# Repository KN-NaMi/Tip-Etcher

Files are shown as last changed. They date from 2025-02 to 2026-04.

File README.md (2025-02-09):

# Tip Etcher for Scanning Tunneling Microscopy (STM)

## Overview
This project is a **Tip Etcher** designed for the fabrication of fine tungsten tips required for **Scanning Tunneling Microscopy (STM)**. The inspiration for this project comes from the [Zyrus Tip Etcher](https://hackaday.io/project/191941-zyrus-tip-etcher-for-scanning-tunneling-microscopy) project, with modifications to improve performance and usability.

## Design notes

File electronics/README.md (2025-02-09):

# PCB Design

This folder contains the PCB design files for the Tip Etcher.

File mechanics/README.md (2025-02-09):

# 3D Model

This folder contains the 3D model files for the Tip Etcher assembly. These models are useful for visualization, 3D printing, and mechanical integration.

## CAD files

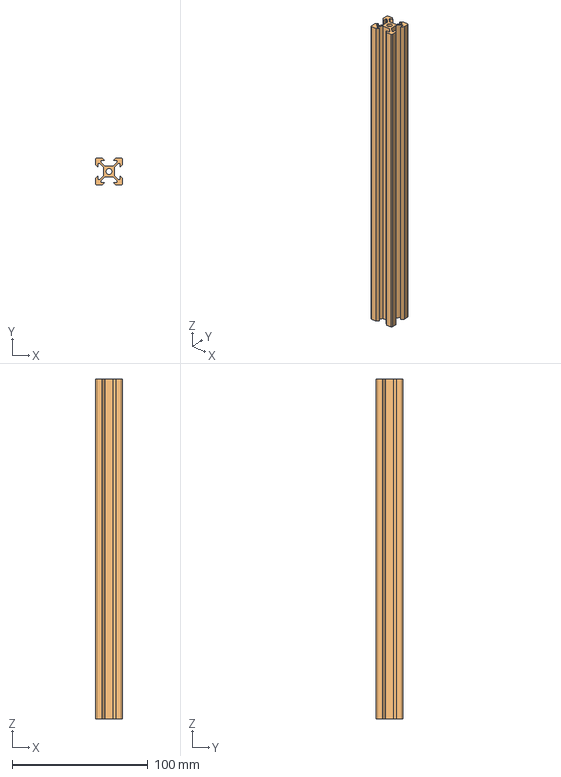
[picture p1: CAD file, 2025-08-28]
mechanics/frame/assembly-frame.FCStd
20.0 x 20.0 x 250.0 mm
2020_150mm v2
2020_250mm v2

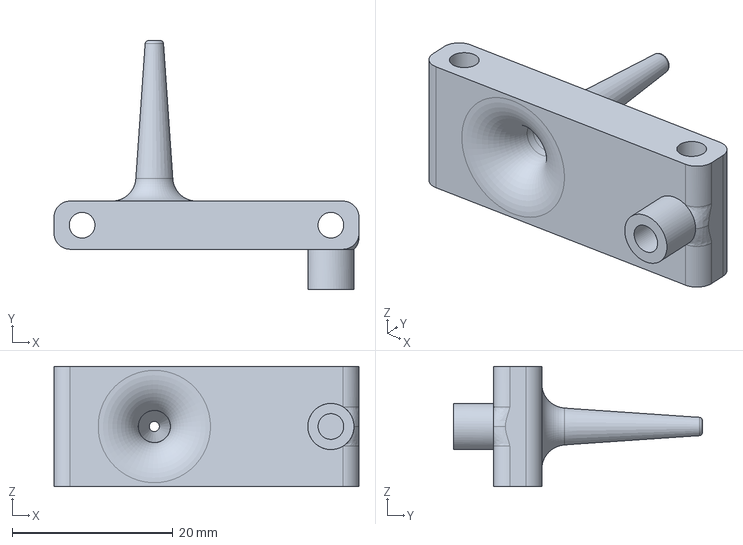
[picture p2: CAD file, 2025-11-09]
cad/mechanism/funnel.FCStd
38.0 x 31.0 x 15.0 mm

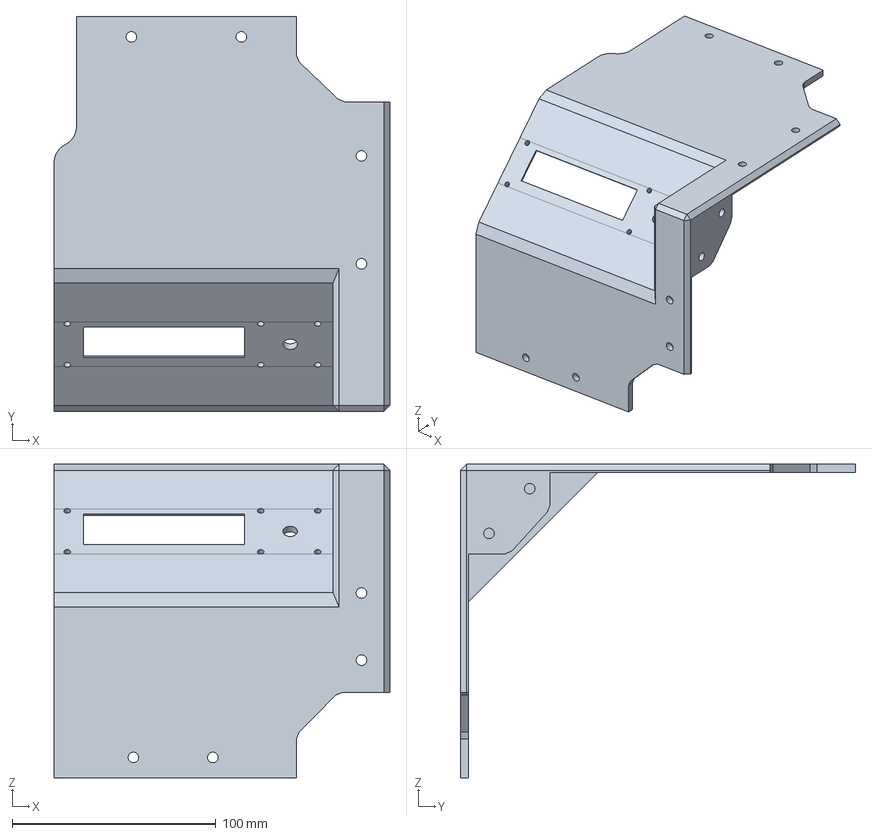
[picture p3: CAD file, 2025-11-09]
cad/Screen/Screen_v3.FCStd
165.0 x 194.0 x 154.0 mm

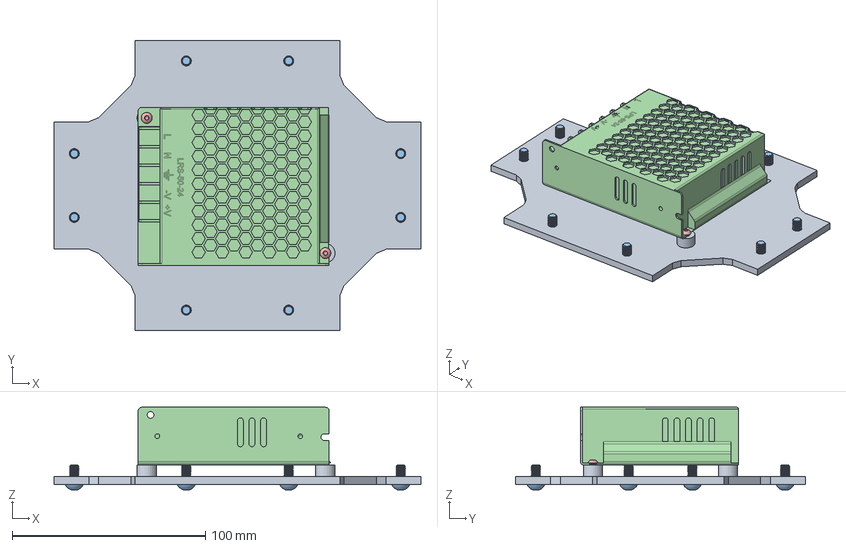
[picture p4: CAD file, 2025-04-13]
mechanics/power-supply/psu-mount.FCStd
190.0 x 150.0 x 42.8 mm
mount
M3x5.74-Insert x 2
M5x10-Screw x 8
MW LRS-50-24
M3x6-Screw x 2

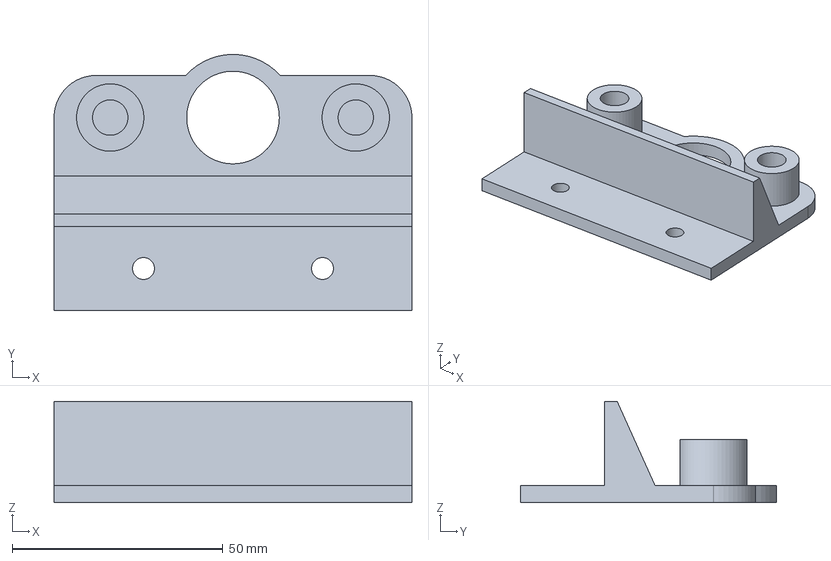
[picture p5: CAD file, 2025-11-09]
cad/mechanism/top.FCStd
85.0 x 60.8 x 24.0 mm

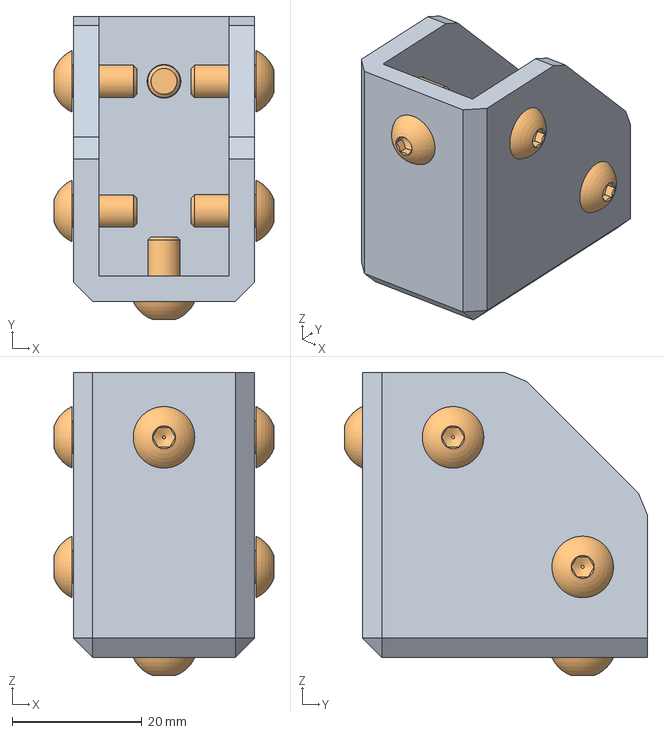
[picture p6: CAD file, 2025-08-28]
mechanics/frame/L-mount.FCStd
33.9 x 46.8 x 46.8 mm
M5x10-Screw x 6

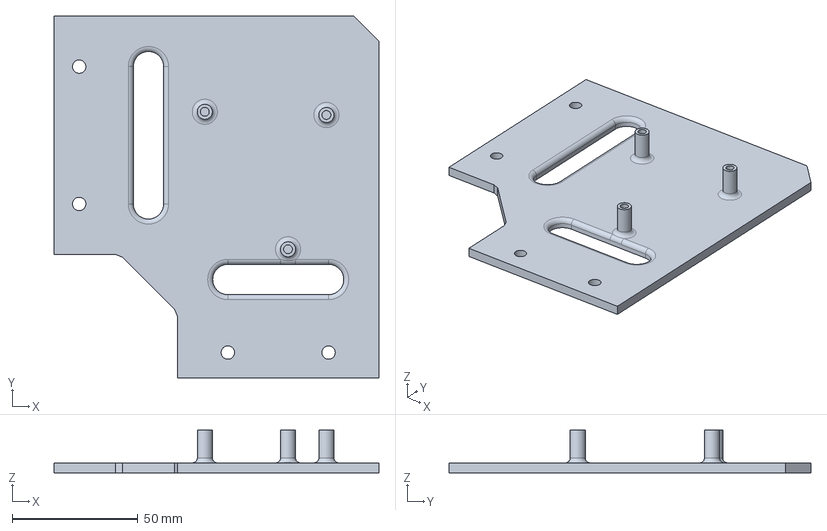
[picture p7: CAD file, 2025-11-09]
cad/mechanism/stm_mount.FCStd
129.0 x 143.5 x 17.0 mm

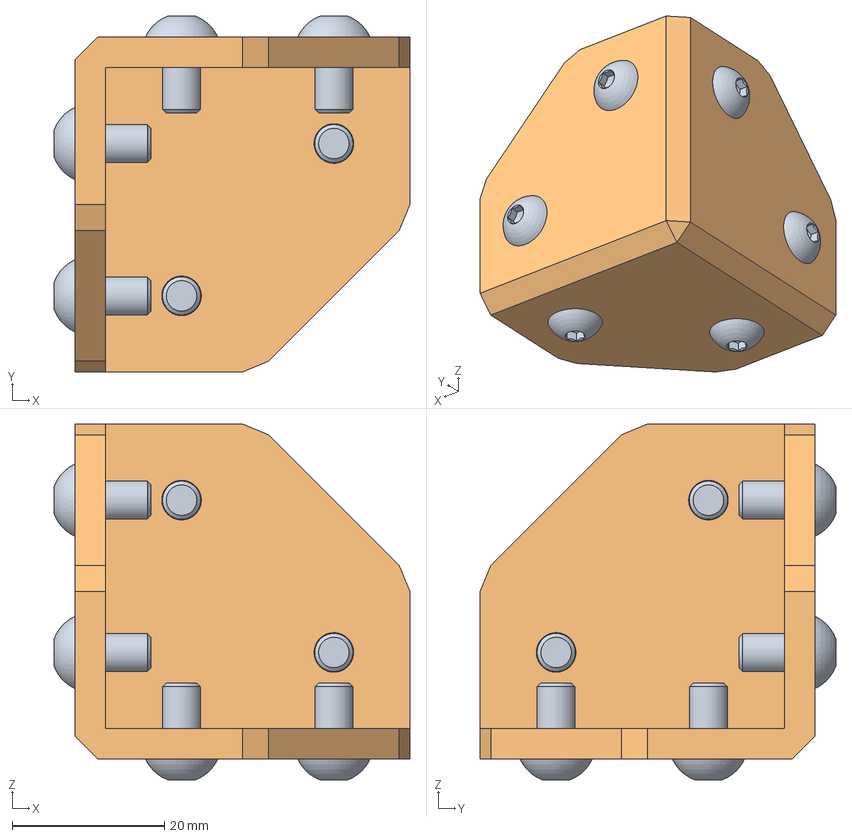
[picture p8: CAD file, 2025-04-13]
mechanics/frame/corner-mount.FCStd
46.8 x 46.8 x 46.8 mm
M5x10-Screw x 6

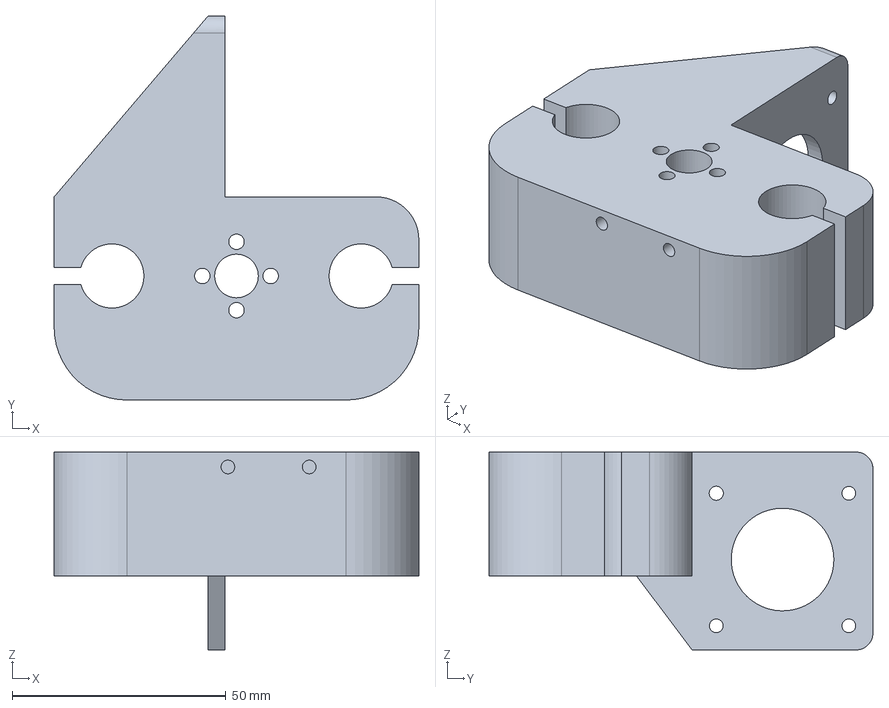
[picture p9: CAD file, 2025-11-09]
cad/mechanism/head.FCStd
85.3 x 89.8 x 46.3 mm

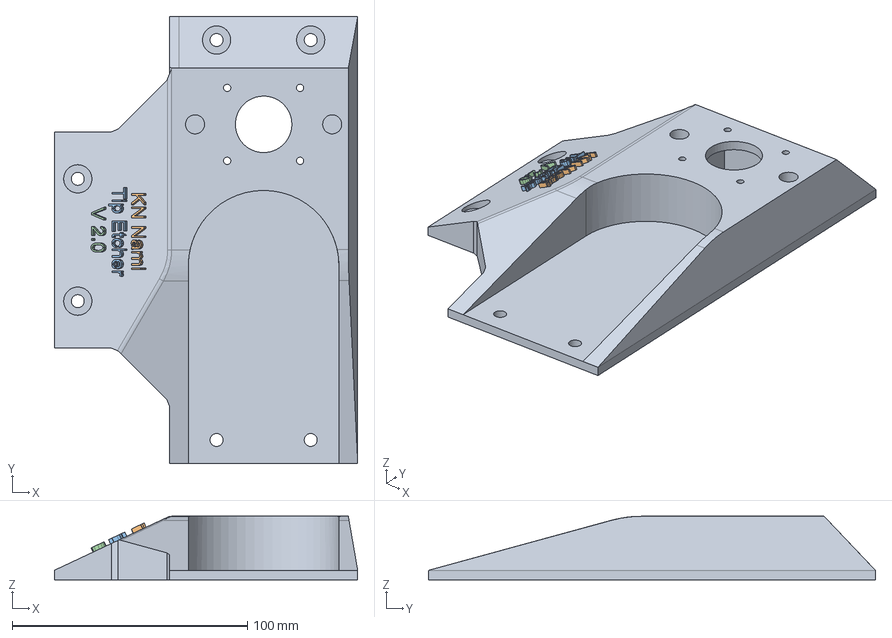
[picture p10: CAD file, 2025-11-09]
cad/mechanism/base.FCStd
129.0 x 190.0 x 27.0 mm

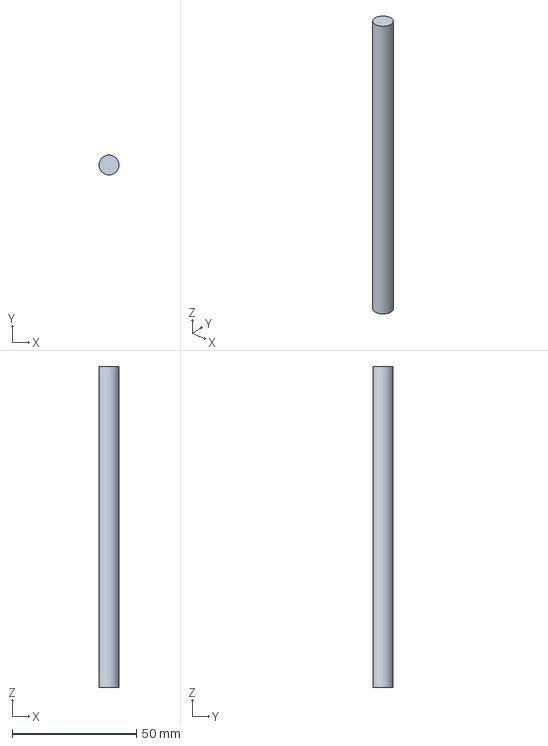
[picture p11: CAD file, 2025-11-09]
cad/mechanism/rod.FCStd
7.99 x 8.00 x 129.0 mm

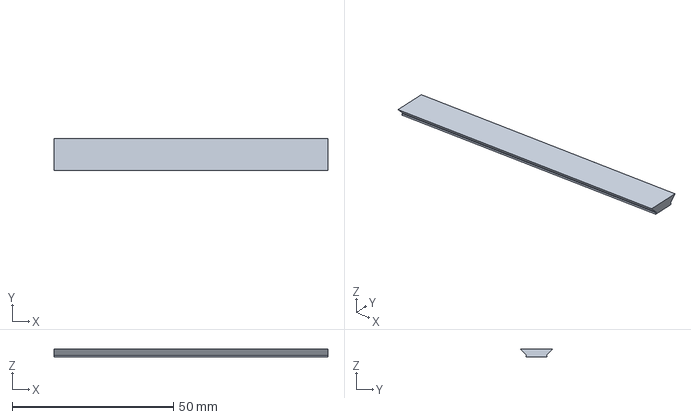
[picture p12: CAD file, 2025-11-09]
cad/mechanism/profile_cover.FCStd
85.0 x 10.0 x 2.50 mm

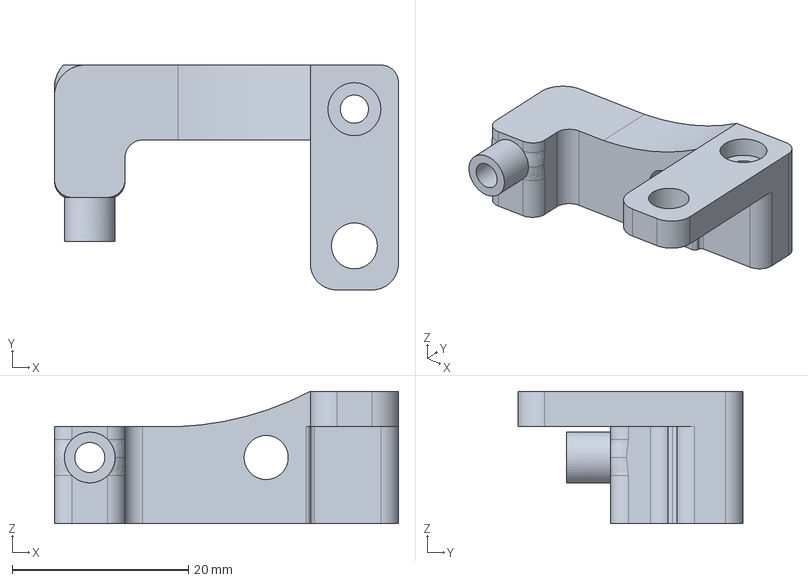
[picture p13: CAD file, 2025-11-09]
cad/mechanism/bearing_holder.FCStd
39.0 x 25.5 x 15.0 mm

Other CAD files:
mechanics/tip-etcher.FCStd

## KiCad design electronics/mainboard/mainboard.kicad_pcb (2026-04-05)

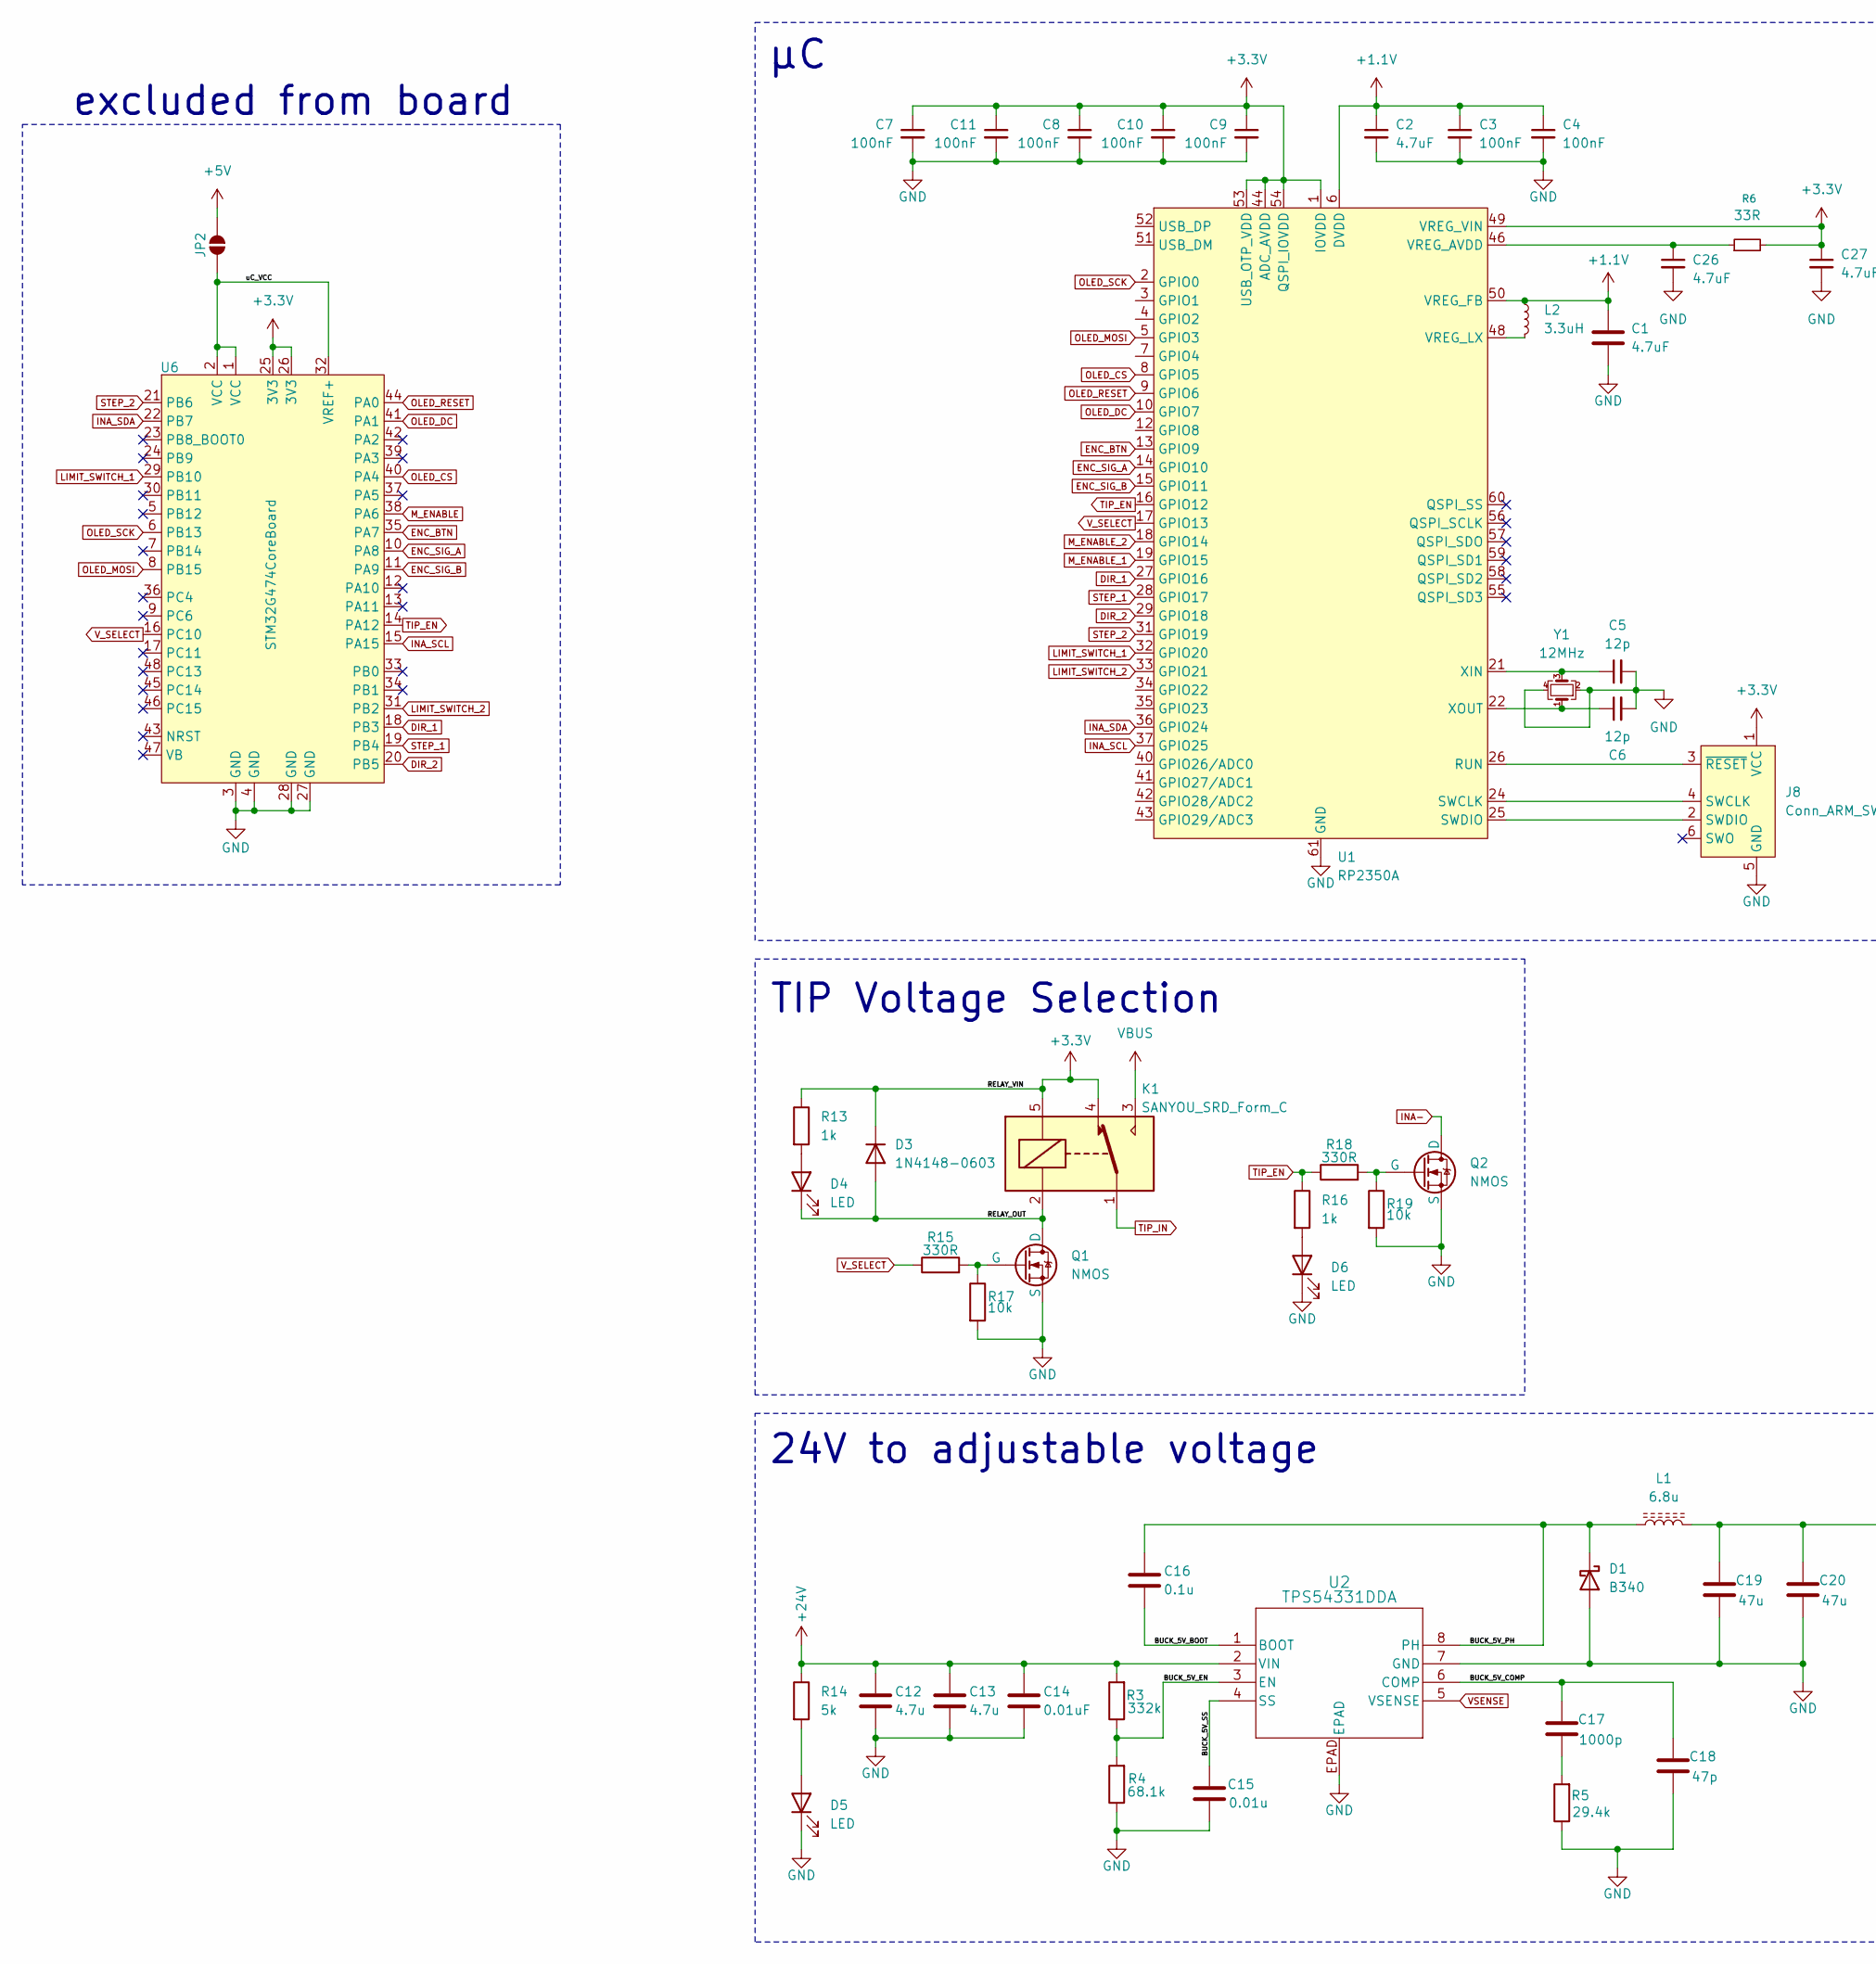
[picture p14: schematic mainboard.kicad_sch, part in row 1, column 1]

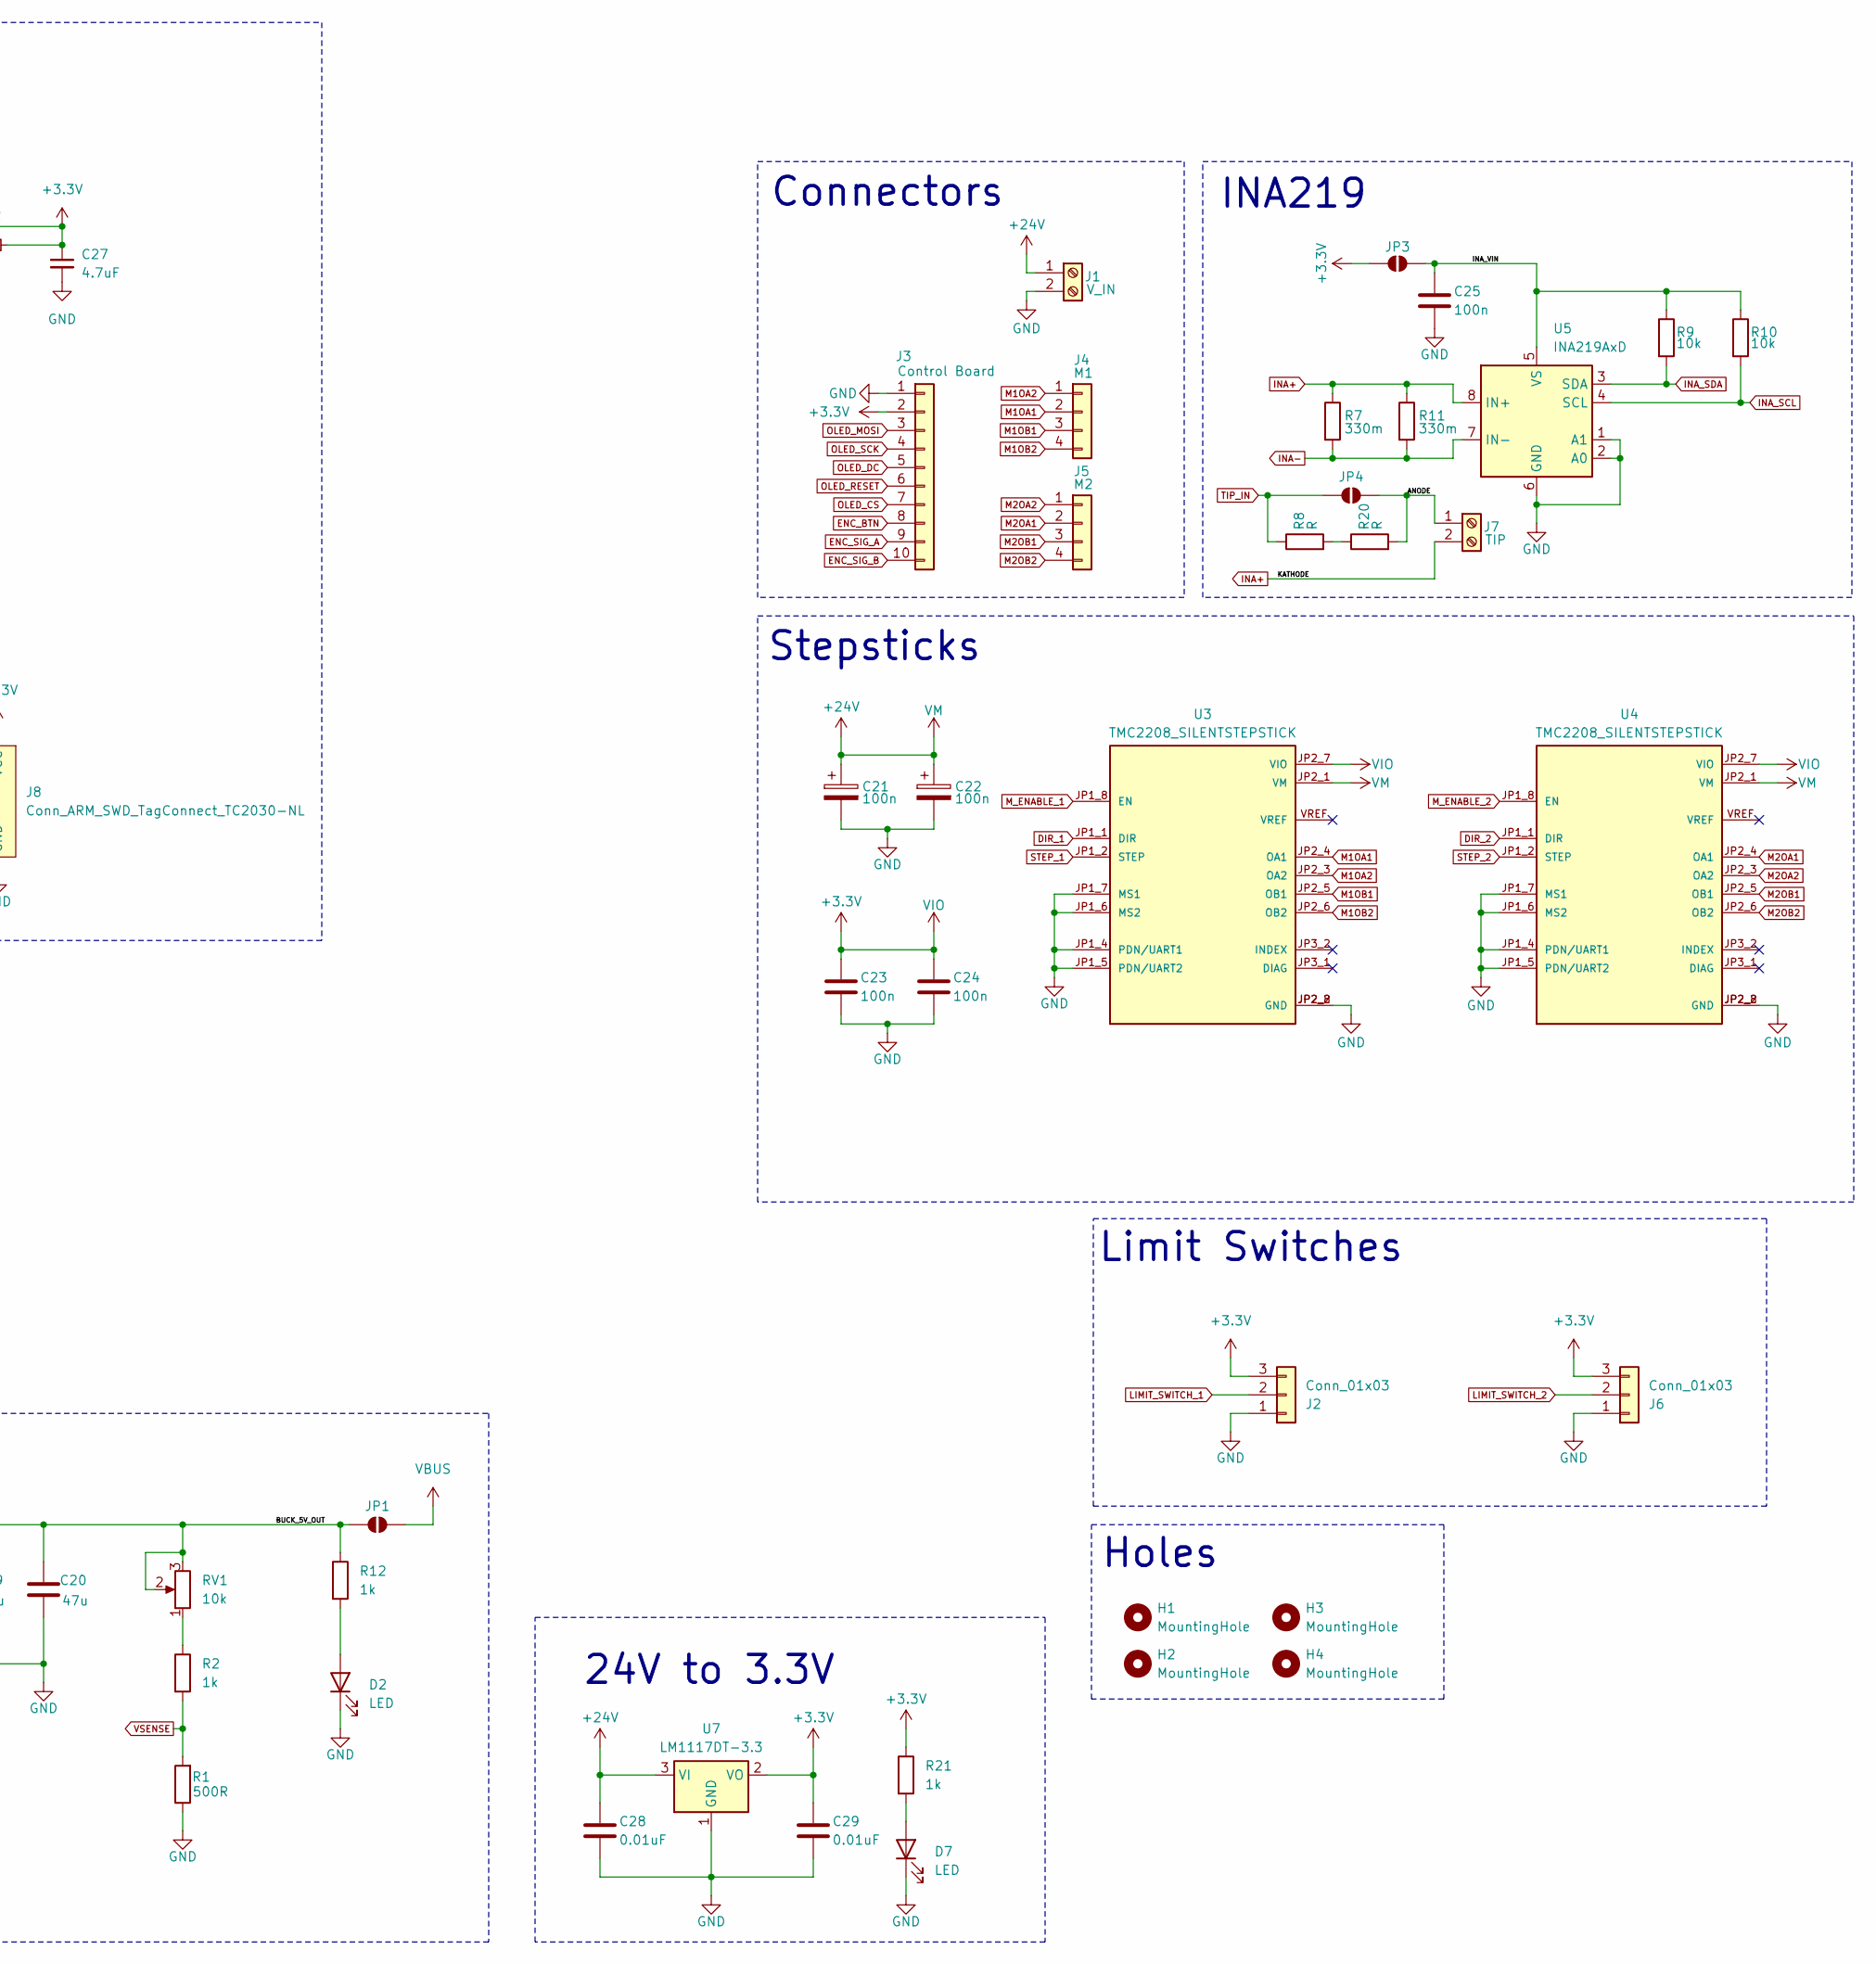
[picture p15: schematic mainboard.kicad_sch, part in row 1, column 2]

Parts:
C1, C2, C26, C27: 4.7uF; C_0805_2012Metric_Pad1.18x1.45mm_HandSolder
C3, C4, C7, C8, C9, C10, C11: 100nF; C_0805_2012Metric_Pad1.18x1.45mm_HandSolder
C5, C6: 12p; C_0805_2012Metric_Pad1.18x1.45mm_HandSolder
C12, C13: 4.7u; C_0603_1608Metric_Pad1.08x0.95mm_HandSolder
C14, C28, C29: 0.01uF; C_0603_1608Metric_Pad1.08x0.95mm_HandSolder
C15: 0.01u; C_0603_1608Metric_Pad1.08x0.95mm_HandSolder
C16: 0.1u; C_0603_1608Metric_Pad1.08x0.95mm_HandSolder
C17: 1000p; C_0603_1608Metric_Pad1.08x0.95mm_HandSolder
C18: 47p; C_0603_1608Metric_Pad1.08x0.95mm_HandSolder
C19, C20: 47u; C_0603_1608Metric_Pad1.08x0.95mm_HandSolder
C21, C22: 100n; CP_Elec_6.3x7.7
C23, C24, C25: 100n; C_0603_1608Metric_Pad1.08x0.95mm_HandSolder
D1: B340; D_SMC
D2, D4, D5, D6, D7: LED; LED_0603_1608Metric_Pad1.05x0.95mm_HandSolder
D3: 1N4148-0603; D_1206_3216Metric
H1, H2, H3, H4: MountingHole; MountingHole_3.2mm_M3
J1: V_IN; CONN_395011002_MOL
J2, J6: Conn_01x03; PinSocket_1x03_P2.54mm_Vertical
J3: Control Board; PinSocket_1x10_P2.00mm_Vertical
J4: M1; PinSocket_1x04_P2.54mm_Vertical
J5: M2; PinSocket_1x04_P2.54mm_Vertical
J7: TIP; CONN_395011002_MOL
J8: Conn_ARM_SWD_TagConnect_TC2030-NL; Tag-Connect_TC2030-IDC-NL_2x03_P1.27mm_Vertical
JP1, JP2, JP3, JP4: SolderJumper_2_Open; SolderJumper-2_P1.3mm_Open_TrianglePad1.0x1.5mm
K1: SANYOU_SRD_Form_C; Relay_SPDT_SANYOU_SRD_Series_Form_C
L1: 6.8u; IND_IHLP-2525CZ_VIS-M
L2: 3.3uH; L_Neosid_SMs42
Q1, Q2: NMOS; SOT-23_Handsoldering
R1: 500R; R_0603_1608Metric_Pad0.98x0.95mm_HandSolder
R2, R12, R13, R16, R21: 1k; R_0603_1608Metric_Pad0.98x0.95mm_HandSolder
R3: 332k; R_0603_1608Metric_Pad0.98x0.95mm_HandSolder
R4: 68.1k; R_0603_1608Metric_Pad0.98x0.95mm_HandSolder
R5: 29.4k; R_0603_1608Metric_Pad0.98x0.95mm_HandSolder
R6: 33R; R_0805_2012Metric_Pad1.20x1.40mm_HandSolder
R7, R11: 330m; D_2512_6332Metric_Pad1.52x3.35mm_HandSolder
R8, R20: R; D_2512_6332Metric_Pad1.52x3.35mm_HandSolder
R9, R10, R17, R19: 10k; R_0603_1608Metric_Pad0.98x0.95mm_HandSolder
R14: 5k; R_0603_1608Metric_Pad0.98x0.95mm_HandSolder
R15, R18: 330R; R_0603_1608Metric_Pad0.98x0.95mm_HandSolder
RV1: 10k; Potentiometer_Vishay_T93YA_Vertical
U1: RP2350A; QFN-60-1EP_7x7mm_P0.4mm_EP3.4x3.4mm_ThermalVias
U2: TPS54331DDA; DDA8_3X2P13
U3, U4: TMC2208_SILENTSTEPSTICK; MODULE_TMC2208_SILENTSTEPSTICK
U5: INA219AxD; SOIC-8_3.9x4.9mm_P1.27mm
U6: STM32G474CoreBoard
U7: LM1117DT-3.3; SOT-223-3_TabPin2
Y1: 12MHz; Crystal_SMD_Abracon_ABM8AIG-4Pin_3.2x2.5mm

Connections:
+1.1V: C1.1, C2.1, C3.1, C4.1, L2.1, U1.6 (DVDD), U1.23 (DVDD), U1.39 (DVDD), U1.50 (VREG_FB)
+3.3V: C7.1, C8.1, C9.1, C10.1, C11.1, C23.1, C24.1, C27.1, C29.1, D3.1 (K), J2.3, J3.2, J6.3, J8.1 (VCC), JP3.1 (A), K1.4, K1.5, R6.2, R13.1, R21.1, U1.1 (IOVDD), U1.11 (IOVDD), U1.20 (IOVDD), U1.30 (IOVDD), U1.38 (IOVDD), U1.44 (ADC_AVDD), U1.45 (IOVDD), U1.49 (VREG_VIN), U1.53 (USB_OTP_VDD), U1.54 (QSPI_IOVDD), U3.JP2_7 (VIO), U4.JP2_7 (VIO), U6.25 (3V3), U6.26 (3V3), U7.2 (VO)
+24V: C12.1, C13.1, C14.1, C21.1, C22.1, C28.1, J1.1, R3.2, R14.1, U2.2 (VIN), U3.JP2_1 (VM), U4.JP2_1 (VM), U7.3 (VI)
/ANODE: J7.1, JP4.2 (B), R20.2
/BUCK_5V_BOOT: C16.2, U2.1 (BOOT)
/BUCK_5V_COMP: C17.1, C18.1, U2.6 (COMP)
/BUCK_5V_EN: R3.1, R4.2, U2.3 (EN)
/BUCK_5V_PH: C16.1, D1.1 (K), L1.1, U2.8 (PH)
/BUCK_5V_SS: C15.1, U2.4 (SS)
/INA_VIN: C25.1, JP3.2 (B), R9.1, R10.1, U5.5 (VS)
/RELAY_OUT: D3.2 (A), D4.1 (K), K1.2, Q1.3 (D)
DIR_1: U1.27 (GPIO16), U3.JP1_1 (DIR), U6.18 (PB3)
DIR_2: U1.29 (GPIO18), U4.JP1_1 (DIR), U6.20 (PB5)
ENC_BTN: J3.8, U1.13 (GPIO9), U6.35 (PA7)
ENC_SIG_A: J3.9, U1.14 (GPIO10), U6.10 (PA8)
ENC_SIG_B: J3.10, U1.15 (GPIO11), U6.11 (PA9)
GND: C1.2, C2.2, C3.2, C4.2, C5.2, C6.2, C7.2, C8.2, C9.2, C10.2, C11.2, C12.2, C13.2, C14.2, C15.2, C18.2, C19.2, C20.2, C21.2, C22.2, C23.2, C24.2, C25.2, C26.2, C27.2, C28.2, C29.2, D1.2 (A), D2.1 (K), D5.1 (K), D6.1 (K), D7.1 (K), J1.2, J2.1, J3.1, J6.1, J8.5 (GND), Q1.2 (S), Q2.2 (S), R1.1, R4.1, R5.1, R17.2, R19.2, U1.47 (VREG_PGND), U1.61 (GND), U2.7 (GND), U2.EPAD, U3.JP1_4 (PDN/UART1), U3.JP1_5 (PDN/UART2), U3.JP1_6 (MS2), U3.JP1_7 (MS1), U3.JP2_2 (GND), U3.JP2_8 (GND), U4.JP1_4 (PDN/UART1), U4.JP1_5 (PDN/UART2), U4.JP1_6 (MS2), U4.JP1_7 (MS1), U4.JP2_2 (GND), U4.JP2_8 (GND), U5.1 (A1), U5.2 (A0), U5.6 (GND), U6.3 (GND), U6.4 (GND), U6.27 (GND), U6.28 (GND), U7.1 (GND), Y1.2, Y1.4; also elsewhere on the board
INA_SCL: R10.2, U1.37 (GPIO25), U5.4 (SCL), U6.15 (PA15)
INA_SDA: R9.2, U1.36 (GPIO24), U5.3 (SDA), U6.22 (PB7)
LIMIT_SWITCH_1: J2.2, U1.32 (GPIO20), U6.29 (PB10)
LIMIT_SWITCH_2: J6.2, U1.33 (GPIO21), U6.31 (PB2)
M1OA1: J4.2, U3.JP2_4 (OA1)
M1OA2: J4.1, U3.JP2_3 (OA2)
M1OB1: J4.3, U3.JP2_5 (OB1)
M1OB2: J4.4, U3.JP2_6 (OB2)
M2OA1: J5.2, U4.JP2_4 (OA1)
M2OA2: J5.1, U4.JP2_3 (OA2)
M2OB1: J5.3, U4.JP2_5 (OB1)
M2OB2: J5.4, U4.JP2_6 (OB2)
M_ENABLE_1: U1.19 (GPIO15), U3.JP1_8 (EN)
M_ENABLE_2: U1.18 (GPIO14), U4.JP1_8 (EN)
unnamed: C17.2, R5.2
unnamed: D2.2 (A), R12.2
unnamed: D4.2 (A), R13.2
unnamed: D5.2 (A), R14.2
unnamed: D6.2 (A), R16.2
unnamed: D7.2 (A), R21.2
unnamed: J8.4 (SWCLK), U1.24 (SWCLK)
unnamed: J8.2 (SWDIO), U1.25 (SWDIO)
unnamed: J8.3 (~RESET), U1.26 (RUN)
unnamed: JP2.2 (B), U6.1 (VCC), U6.2 (VCC), U6.32 (VREF+)
unnamed: Q1.1 (G), R15.2, R17.1
unnamed: Q2.1 (G), R18.2, R19.1
unnamed: R2.1, RV1.1
unnamed: R8.2, R20.1
unnamed: C26.1, R6.1, U1.46 (VREG_AVDD)
unnamed: L2.2, U1.48 (VREG_LX)
unnamed: C5.1, U1.21 (XIN), Y1.3
unnamed: C6.1, U1.22 (XOUT), Y1.1
OLED_CS: J3.7, U1.8 (GPIO5), U6.40 (PA4)
OLED_DC: J3.5, U1.10 (GPIO7), U6.41 (PA1)
OLED_MOSI: J3.3, U1.5 (GPIO3), U6.8 (PB15)
OLED_RESET: J3.6, U1.9 (GPIO6), U6.44 (PA0)
OLED_SCK: J3.4, U1.2 (GPIO0), U6.6 (PB13)
STEP_1: U1.28 (GPIO17), U3.JP1_2 (STEP), U6.19 (PB4)
STEP_2: U1.31 (GPIO19), U4.JP1_2 (STEP), U6.21 (PB6)
TIP_EN: R16.1, R18.1, U1.16 (GPIO12), U6.14 (PA12)
TIP_IN: JP4.1 (A), K1.1, R8.1
VBUS: JP1.2 (B), K1.3
V_SELECT: R15.1, U1.17 (GPIO13), U6.16 (PC10)

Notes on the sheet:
Connectors
excluded from board
TIP Voltage Selection
24V to adjustable voltage
Limit Switches
INA219
24V to 3.3V
Stepsticks
Holes

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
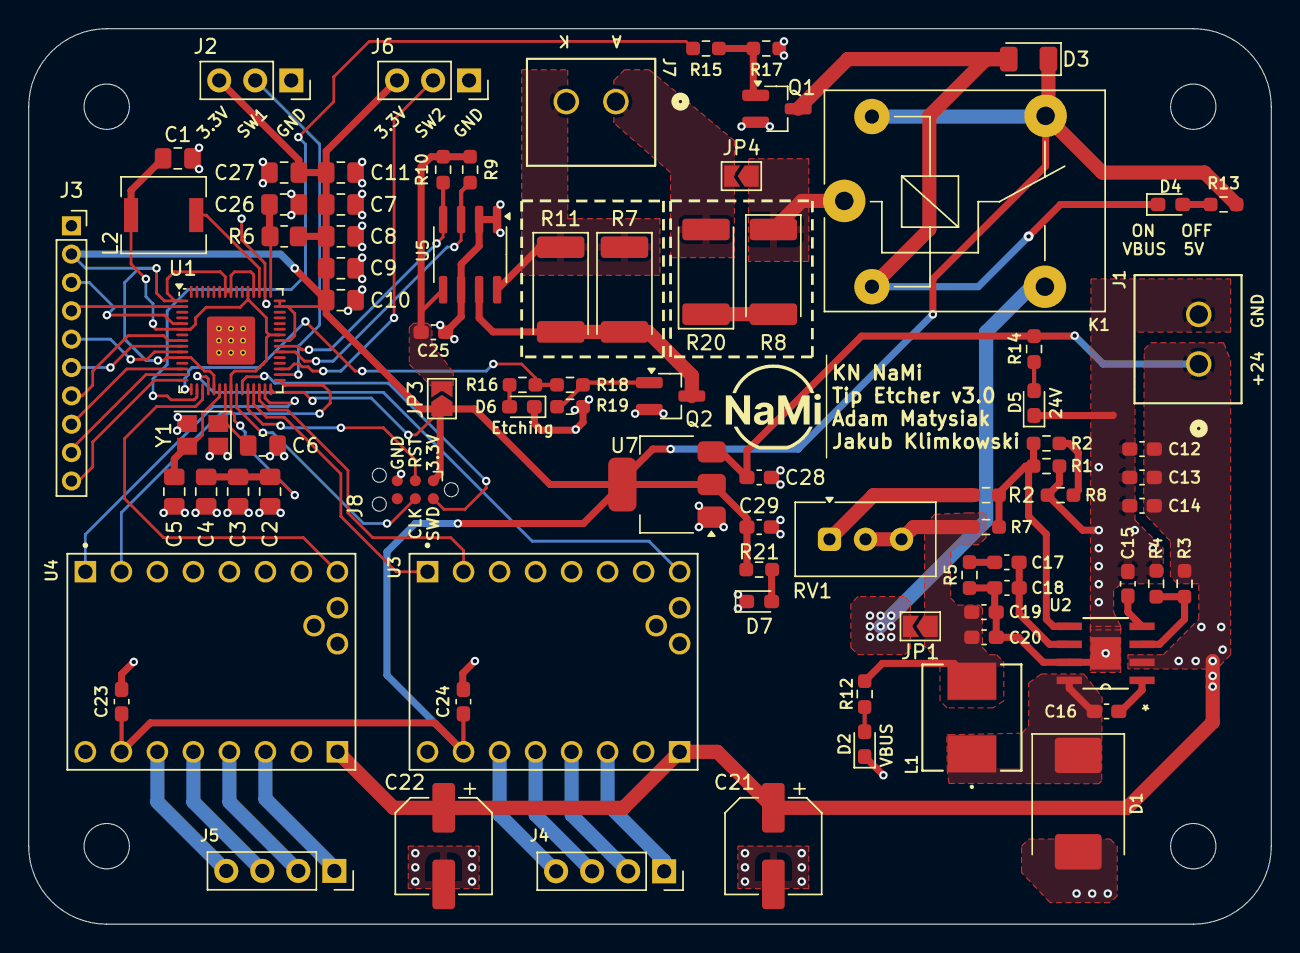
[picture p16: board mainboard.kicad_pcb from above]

Board: 2 copper layers, 87.6 x 63.1 mm, 88 parts (0 on the bottom side), 64 nets.

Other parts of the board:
R2#2, R8#2: 1k; R_0603_1608Metric_Pad0.98x0.95mm_HandSolder
R7#2: 330m; D_2512_6332Metric_Pad1.52x3.35mm_HandSolder

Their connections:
GND: R8#2.1; also elsewhere on the board
unnamed: R2#2.1, R8#2.2

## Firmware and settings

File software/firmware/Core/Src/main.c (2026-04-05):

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
/* Includes ------------------------------------------------------------------*/
#include "main.h"

/* USER CODE BEGIN Includes */

#include <stdio.h>

#include "NaMiMenu_lib/NaMiMenu.h"
/* USER CODE END Includes */

I2C_HandleTypeDef hi2c1;

SPI_HandleTypeDef hspi2;

TIM_HandleTypeDef htim2;

void SystemClock_Config(void);
static void MX_GPIO_Init(void);
static void MX_SPI2_Init(void);
static void MX_TIM2_Init(void);
static void MX_I2C1_Init(void);
/* USER CODE BEGIN 0 */
// OLED VARIABLES

// TIP ETCHER VARIBLES

uint16_t var_etchTime = 60;   // s
uint16_t var_depth    = 5000; // um
uint16_t var_step     = 20;   // um
uint16_t var_polishTime = 0; // ms

uint16_t etchTime_cnt = 0;
uint16_t stepTime_cnt = 0;

uint16_t polishTime_cnt = 0;
int etchStartPosition = 0;

//

uint16_t var_current = 100;
uint8_t progress_bar = 0;

double test_chart_data[100] = {
	//0, 1, 2, 4, 8, 16, 20, 28, 24, -10, -5, -4, -3, -2, -1, -14, -15, -20, -20, -20, 15, 16, 17
};

uint8_t dataCounter = 0;
uint8_t iterator = 0;

Chart test_chart = {
		test_chart_data,
		sizeof(test_chart_data) / sizeof(double),
		50,
		0
};

ProgressBar bar1 = {255 / 2, 0};

typedef struct Motor {
	int pos;
	int setPos;
    GPIO_TypeDef* dir_port;
    uint16_t dir_pin;
    GPIO_TypeDef* step_port;
    uint16_t step_pin;
} Motor;

// 23.2u / krok
Motor Motor1 = {0, 0, DIR_1_GPIO_Port, DIR_1_Pin, STEP_1_GPIO_Port, STEP_1_Pin};
Motor Motor2 = {0, 0, DIR_2_GPIO_Port, DIR_2_Pin, STEP_2_GPIO_Port, STEP_2_Pin};

//uint8_t current_value = 0;

void StateTransision(uint8_t nextState);

void voltage_select(State *state, Clickable *clickable);
void etching_enable(State *state, Clickable *clickable);

void led_toggle(State *state, Clickable *clickable);
void etching_start_stop(State *state, Clickable *clickable);
void settings_toggle_cursor(State *state, Clickable *clickable);
void settings_voltage_select(State *state, Clickable *clickable);
void Update_Menu();
void Update_Settings();
void Update_Manual();
void Motor2_Home();

void Update_Debug();


void INA219_Init();

void INA219_ReadCurrent();

// =======================================================

void Tip_Enable() {
	HAL_GPIO_WritePin(TIP_EN_GPIO_Port, TIP_EN_Pin, 1);
}
void Tip_Disable() {
	HAL_GPIO_WritePin(TIP_EN_GPIO_Port, TIP_EN_Pin, 0);
}
void Tip_5V() {
	HAL_GPIO_WritePin(V_SELECT_GPIO_Port, V_SELECT_Pin, 0);
}
void Tip_24V() {
	HAL_GPIO_WritePin(V_SELECT_GPIO_Port, V_SELECT_Pin, 1);
}

// ETCHING ===============================================

uint8_t etching = 0;
uint16_t etchingTime = 10;
uint16_t currentValue = 0;


double currentValue2 = 0;
double currentMiliAmp = 0;
double minCurrentMiliAmp = 0.4;

double Tip_Current() {
	return currentMiliAmp;
}

uint8_t frame[2] = {0, 0};

enum Etching_States {
	None,
	IDLE,
	HEAD_DOWN,
	TIP_DOWN,
	TIP_EXTEND,
	HOMING,
	APPROACH,
	DIVE,
	ETCH,
	POLISH
};

enum Etching_States currentEtchingState = None;
enum Etching_States nextEtchingState    = None;

void StateTransision(uint8_t nextState) {
	currentEtchingState = nextState;
}

int SelectState(enum Etching_States state) {
	if(nextEtchingState == state && nextEtchingState != currentEtchingState) {
		currentEtchingState = nextEtchingState;
		NAL_NaMiMenu_OLED_Update();
		return 1;
	} return 0;
}

// MENU ===============================================

enum Menu_States {
	NONE,
	Menu,
	Settings,
	Manual,
	Debug
};

Clickable menu_clickable[] = {
	{NONE, NULL, ""},
	{NONE, &etching_start_stop, "Start"},
	{Settings, NULL, "Settings"},
	{Manual, NULL, "Manual"},
	{Debug, NULL, "Debug"},
	{NONE, &INA219_ReadCurrent, "R Current"}
};

Clickable debug_clickable[] = {
	{None, NULL, "Stop"},
	{NONE, NULL, "LowerHead"},
	{NONE, NULL, "LowerTip"},
	{NONE, NULL, "LiftHead"},
	{NONE, NULL, "LowerHeadAndEtch"},
	{Menu, NULL, "Back"}
};

Clickable manual_clickable[] = {
	{NONE, NULL, ""},
	{NONE, &voltage_select, "Relay"},
	{NONE, &NAL_NaMiMenu_Cursor_toggle_freeze, "Motor1"},
	{NONE, &NAL_NaMiMenu_Cursor_toggle_freeze, "Motor2"},
	{NONE, &etching_enable, "Etch. En."},
	{NONE, &Motor2_Home, "Home Motor2"},
	{Menu, NULL, "Back"}
};

Clickable settings_clickable[] = {
	{NONE, &settings_toggle_cursor, "Etching time"},
	{NONE, &settings_toggle_cursor, "Depth"},
	{NONE, &settings_toggle_cursor, "Step"},
	{NONE, &settings_voltage_select, "voltage"},
	{NONE, &settings_toggle_cursor, "Polish time"},
	{NONE, &settings_toggle_cursor, "Max current"},
	{Menu, NULL, "Back"}
};

State states[] = {
	{Menu, &Update_Menu, menu_clickable, ARRAY_SIZE(menu_clickable)},
	{Settings, &Update_Settings, settings_clickable, ARRAY_SIZE(settings_clickable)},
	{Manual, &Update_Manual, manual_clickable, ARRAY_SIZE(manual_clickable)},
	{Debug, &Update_Debug, debug_clickable, ARRAY_SIZE(debug_clickable)}
};

int voltageSelection = 0;

void settings_voltage_select(State *state, Clickable *clickable) {
	voltageSelection = !voltageSelection;
}

void Update_Debug() { }

void Update_Menu() {

	//NAL_draw_indicator_in_grid(HAL_GPIO_ReadPin(LED_GPIO_Port, LED_Pin), 13, 0, 5);
	//NAL_draw_text_in_grid("5V", 14, 0, 5);
	//NAL_draw_indicator_in_grid(!HAL_GPIO_ReadPin(LED_GPIO_Port, LED_Pin), 13, 1, 5);
	//NAL_draw_text_in_grid("24V", 14, 1, 5);

	char text1[24];
	//sprintf(text1, "%d", currentValue);

	int miliAmp = currentValue2 / 1000.0;
	int nanoAmp = (int)((currentValue2 - miliAmp * 1000.0));

	char nanoAmpText[16];

	if(miliAmp < 0)
		miliAmp = 0;

	if(nanoAmp < 0)
		nanoAmp = 0;

	if(nanoAmp >= 100)
		sprintf(nanoAmpText, "%d", nanoAmp);
	if(nanoAmp < 100)
		sprintf(nanoAmpText, "0%d", nanoAmp);
	else if(nanoAmp < 10)
		sprintf(nanoAmpText, "00%d", nanoAmp);
	else if(nanoAmp < 1)
		sprintf(nanoAmpText, "000");

	sprintf(text1, "%d,%s mA", miliAmp, nanoAmpText);
	//sprintf(text1, "%d | %d", frame[0], frame[1]);
	NAL_draw_text_in_grid(text1, 8, 0, 5);
	test_chart_data[dataCounter++ % 100] = miliAmp;

	if(!etching)
		NAL_draw_text_in_grid("Idle", 5, 0, 5);
	else {
		sprintf(text1, "T: %d", var_etchTime - etchTime_cnt * 2 / 1000);
		NAL_draw_text_in_grid(text1, 5, 0, 5);
	}

	NAL_draw_chart_in_grid(&test_chart, 5, 1, 8, 3, 5);

	//NAL_draw_progress_bar(&bar1);
}

void Update_Settings() {
	char text1[16];

	// Etching time
	sprintf(text1, "%d s", var_etchTime);
	NAL_draw_text_in_grid(text1, 8, 0, 5);
	// Depth
	sprintf(text1, "%d um", var_depth);
	NAL_draw_text_in_grid(text1, 8, 1, 5);
	// Step
	sprintf(text1, "%d um", var_step);
	NAL_draw_text_in_grid(text1, 8, 2, 5);
	// Voltage Selection
	if(voltageSelection) {
		NAL_draw_text_in_grid("5 V", 8, 3, 5);
	} else {
		NAL_draw_text_in_grid("24 V", 8, 3, 5);
	}
	// Max current
	//sprintf(text1, "%d mA", var_current);
	//NAL_draw_text_in_grid(text1, 8, 3, 5);
	// Polish time
	sprintf(text1, "%d ms", var_polishTime);
	NAL_draw_text_in_grid(text1, 12, 0, 5);
}

void Update_Manual() {
	NAL_draw_indicator_in_grid(!HAL_GPIO_ReadPin(V_SELECT_GPIO_Port, V_SELECT_Pin), 8, 0, 5);
	NAL_draw_text_in_grid("5V", 9, 0, 5);
	NAL_draw_indicator_in_grid(HAL_GPIO_ReadPin(V_SELECT_GPIO_Port, V_SELECT_Pin), 11, 0, 5);
	NAL_draw_text_in_grid("24V", 12, 0, 5);
	//
	NAL_draw_indicator_in_grid(!HAL_GPIO_ReadPin(LIMIT_SWITCH_1_GPIO_Port, LIMIT_SWITCH_1_Pin), 7, 2, 5);
	char text1[16];
	sprintf(text1, "%d", Motor1.setPos);
	NAL_draw_text_in_grid(text1, 8, 1, 5);
//	sprintf(text1, "%d", Motor1.pos);
//	NAL_draw_text_in_grid(text1, 12, 1, 5);
	//
	sprintf(text1, "%d", Motor2.setPos);
	NAL_draw_text_in_grid(text1, 8, 2, 5);
//	sprintf(text1, "%d", Motor2.pos);
//	NAL_draw_text_in_grid(text1, 12, 2, 5);
	//
	NAL_draw_indicator_in_grid(HAL_GPIO_ReadPin(TIP_EN_GPIO_Port, TIP_EN_Pin), 8, 3, 5);
	NAL_draw_text_in_grid("Electrode", 9, 3, 5);
}

void Motor2_Home() {
	Motor2.setPos = 10000;
}

void voltage_select(State *state, Clickable *clickable) {
	HAL_GPIO_TogglePin(V_SELECT_GPIO_Port, V_SELECT_Pin);
}

void etching_enable(State *state, Clickable *clickable) {
	HAL_GPIO_TogglePin(TIP_EN_GPIO_Port, TIP_EN_Pin);
}

void led_toggle(State *state, Clickable *clickable) {
	HAL_GPIO_TogglePin(LED_GPIO_Port, LED_Pin);
}

uint8_t motor1Pos;

void etching_start_stop(State *state, Clickable *clickable) {
	etching = !etching;

	if(etching) {
		//clickable->text = "Stop";
		//NAL_NaMiMenu_Cursor_freeze();
		//currentEtchingState = HEAD_DOWN;
		motor1Pos = Motor1.setPos;
	}
	else {
		//clickable->text = "Start";
		//NAL_NaMiMenu_Cursor_unfreeze();
	}
}

void settings_toggle_cursor(State *state, Clickable *clickable) {
	NAL_NaMiMenu_Cursor_toggle_freeze();
}

void NAL_FrozenCursorMove_Callback(State *state, Clickable *clickable) {

	if(state->state == Settings) {

		switch(NAL_NaMiMenu_CursorPos()) {
		case 0: // Etching time
			var_etchTime = NAL_NaMiMenu_CursorDir() ? var_etchTime + 1 : var_etchTime - 1;
			break;
		case 1: // Depth
			var_depth = NAL_NaMiMenu_CursorDir() ? var_depth + 100 : var_depth - 100;
			break;
		case 2: // Step
			var_step = NAL_NaMiMenu_CursorDir() ? var_step + 5 : var_step - 5;
			break;
		case 5: // Max current
			//if(NAL_NaMiMenu_CursorDir()) { var_current++; } else { var_current--; }
			var_current = NAL_NaMiMenu_CursorDir() ? var_current + 1 : var_current - 1;
			break;
		case 4: // Polish time
			var_polishTime = NAL_NaMiMenu_CursorDir() ? var_polishTime + 10 : var_polishTime - 10;
			break;
		}
	}

	if(state->state == Manual) {
		if(NAL_NaMiMenu_CursorPos() == 2) {
			if(NAL_NaMiMenu_CursorDir()) {
				Motor1.setPos += 100;
			} else {
				Motor1.setPos -= 100;
			}
		}

		if(NAL_NaMiMenu_CursorPos() == 3) {
			if(NAL_NaMiMenu_CursorDir()) {
				Motor2.setPos += 10;
			} else {
				Motor2.setPos -= 10;
			}
		}
	}

	if(state->state == Menu && NAL_NaMiMenu_CursorPos() == 1) {
		if(NAL_NaMiMenu_CursorDir()) {
			if(bar1.value < 255)
				bar1.value += 15;
		} else {
			if(bar1.value > 0)
				bar1.value -= 15;
		}
	}
}

// Callback do wywołania przed wysłaniem buffera do OLED'a

void MoveMotor(Motor *motor) {

	if(motor->pos != motor->setPos) {

		if(motor->pos < motor->setPos) {
			HAL_GPIO_WritePin(motor->dir_port, motor->dir_pin, 0);
			motor->pos++;

			if(!HAL_GPIO_ReadPin(LIMIT_SWITCH_1_GPIO_Port, LIMIT_SWITCH_1_Pin) && motor == &Motor2) {
				Motor2.pos = 0;
				Motor2.setPos = 0;
			}
		} else {
			if(motor == &Motor2 && motor->pos <= -2400) {
				return;
			}
			HAL_GPIO_WritePin(motor->dir_port, motor->dir_pin, 1);
			motor->pos--;
		}

		HAL_GPIO_WritePin(motor->step_port, motor->step_pin, 1);
		HAL_GPIO_WritePin(motor->step_port, motor->step_pin, 0);
	}

}

uint16_t tim_cnt = 0;
uint16_t debounce = 0;

void HAL_TIM_PeriodElapsedCallback(TIM_HandleTypeDef *htim) {
	if(htim == &htim2) { // Updates every 2 ms

		debounce++;

		if(currentEtchingState == ETCH)
			etchingTime++;

		tim_cnt++;
		if((tim_cnt >= 250) && HAL_GPIO_ReadPin(TIP_EN_GPIO_Port, TIP_EN_Pin)) {
			//NAL_NaMiMenu_OLED_Update();
			if(currentEtchingState == ETCH || currentEtchingState == IDLE) {
				INA219_ReadCurrent();
				NAL_NaMiMenu_OLED_Update();
			}
			tim_cnt = 0;
		}

		if(etching && currentEtchingState == ETCH) {
			etchTime_cnt++;
			stepTime_cnt++;
		}

		if(currentEtchingState == POLISH && Motor2.pos == etchStartPosition) {
			polishTime_cnt++;
		}

		MoveMotor(&Motor1);

		MoveMotor(&Motor2);
	}
}

int Motor2_MaxPos() {
	return Motor2.pos <= -2400;
}

int M1startingPos = 0;
int M1maxPos = 12; // mm

int Motor1_MaxPos() {
	return Motor1.pos >= M1startingPos + ((double)(M1maxPos) / 0.0232);
}

void HAL_GPIO_EXTI_Callback(uint16_t GPIO_Pin)
{
	if(GPIO_Pin == NaMiMenu_ENC_BTN.pin && debounce > 10) {
		NAL_NaMiMenu_Encoder_Update(GPIO_Pin);
		debounce = 0;
	} else if(GPIO_Pin != NaMiMenu_ENC_BTN.pin)
		NAL_NaMiMenu_Encoder_Update(GPIO_Pin);
}

void INA219_Init() {
    uint8_t calibration[2];
    uint16_t cal;

    double R_SHUNT = 0.16; // 0.33;  // Ω
    double maxAmp = 0.3;    //

    double current_lsb = maxAmp / 32767.0;
    cal = (uint16_t)(0.04096 / (current_lsb * R_SHUNT));

    calibration[0] = (uint8_t)(cal >> 8);
    calibration[1] = (uint8_t) cal;

    // Zapis kalibracji
    HAL_I2C_Mem_Write(&hi2c1, (0x40 << 1), 0x05, I2C_MEMADD_SIZE_8BIT, calibration, 2, HAL_MAX_DELAY);

    // Ustawienie trybu: 32V / 320mV / 12bit / ciągły
    uint8_t config[2] = {0x01, 0x9F};
    HAL_I2C_Mem_Write(&hi2c1, (0x40 << 1), 0x00, I2C_MEMADD_SIZE_8BIT, config, 2, HAL_MAX_DELAY);
}

void INA219_ReadCurrent() {
    uint8_t data[2];

    HAL_I2C_Mem_Read(&hi2c1, (0x40 << 1), 0x04, I2C_MEMADD_SIZE_8BIT, data, 2, HAL_MAX_DELAY);

    int16_t rawCurrent = (int16_t)((data[0] << 8) | data[1]);

    frame[0] = data[0];
    frame[1] = data[1];

    //double R_SHUNT = 100.0;
    double maxAmp = 0.3;
    double current_lsb = maxAmp / 32767.0;

    double current_A = rawCurrent * current_lsb;

    currentValue2 = current_A * 1000000.0;
    currentMiliAmp = currentValue2 / 1000.0;
}

/* USER CODE END 0 */

/**
  * @brief  The application entry point.
  * @retval int
  */
int main(void)
{

  /* MCU Configuration--------------------------------------------------------*/

  /* Reset of all peripherals, Initializes the Flash interface and the Systick. */
  HAL_Init();

  /* Configure the system clock */
  SystemClock_Config();

  /* Initialize all configured peripherals */
  MX_GPIO_Init();
  MX_SPI2_Init();
  MX_TIM2_Init();
  MX_I2C1_Init();
  /* USER CODE BEGIN 2 */

  HAL_GPIO_WritePin(LED_GPIO_Port, LED_Pin, 1);

  HAL_TIM_Base_Start_IT(&htim2);

  NAL_NaMiMenu_init(OLED_CS_GPIO_Port, OLED_CS_Pin, OLED_DC_GPIO_Port, OLED_DC_Pin, OLED_RESET_GPIO_Port, OLED_RESET_Pin, &hspi2);
  NAL_NaMiMenu_setMenuStates(states, sizeof(states) / sizeof(State));
  NAL_NaMiMenu_Encoder_setup(ENCODER_BTN_GPIO_Port, ENCODER_BTN_Pin, ENCODER_SIGA_GPIO_Port, ENCODER_SIGA_Pin, ENCODER_SIGB_GPIO_Port, ENCODER_SIGB_Pin);

  NAL_NaMiMenu_splash_screen("Tip Etcher", "v2.2 | in dev");

  // Device initialization

  INA219_Init();

  //

  Transision(Menu);

  HAL_GPIO_WritePin(M_ENABLE_GPIO_Port, M_ENABLE_Pin, 0);


  NAL_NaMiMenu_SetCursorPos(1);

  //if(!HAL_GPIO_ReadPin(LIMIT_SWITCH_1_GPIO_Port, LIMIT_SWITCH_1_Pin))
	  //;//NAL_NaMiMenu_Cursor_freeze();

  //Motor2_Home();

  /* USER CODE END 2 */

  /* Infinite loop */
  /* USER CODE BEGIN WHILE */
  while (1)
  {
	  if(etching)
		  INA219_ReadCurrent();

	  switch(nextEtchingState) {

	  case IDLE:
		  if(SelectState(IDLE)) {
			  Tip_Disable();
			  Tip_5V();
			  Motor2_Home();
			  etchTime_cnt = 0;
			  etching = 0;
			  Motor1.setPos = M1startingPos;
		  }
		  // Klinkięto "Start"
		  if(etching) { nextEtchingState = HEAD_DOWN; M1startingPos = Motor1.pos; }
		  break;

	  case HEAD_DOWN:
		  if(SelectState(HEAD_DOWN)) {
			  Tip_5V();
			  Tip_Enable();
		  }
		  // Wykryto taflę cieczy (przepływa prąd).
		  if(Tip_Current() > minCurrentMiliAmp) { nextEtchingState = TIP_EXTEND; }
		  // Osiągnięto pozycję maksymalną M2.
		  if(Motor2_MaxPos()) { nextEtchingState = TIP_DOWN; }

		  if(Motor2.pos == Motor2.setPos) {
			  Motor2.setPos -= 1;
		  }
		  break;

	  case TIP_DOWN:
		  if(SelectState(TIP_DOWN)) {
			  Tip_5V();
			  Tip_Enable();
		  }
		  if(Motor1.pos == Motor1.setPos) {
			  Motor1.setPos += 1;
		  }
		  // Wykryto taflę cieczy (przepływa prąd).
		  if(Tip_Current() > minCurrentMiliAmp) { nextEtchingState = TIP_EXTEND; }
		  // Osiągnięto pozycję maksymalną M1.
		  if(Motor1_MaxPos()) { nextEtchingState = IDLE; }
		  break;

	  case TIP_EXTEND:
		  if(SelectState(TIP_EXTEND)) {
			  Tip_5V();
			  Tip_Disable();
			  Motor1.setPos += ((double)(var_depth + 500) / 23.2);
		  }
		  // Osiągnięto pozycję maksymalną M1.
		  if(Motor1_MaxPos()) { nextEtchingState = IDLE; }
		  if(Motor1.pos >= M1startingPos + ((double)(var_depth) / 23.2)) { nextEtchingState = HOMING; }
		  break;

	  case HOMING:
		  if(SelectState(HOMING)) {
			  Tip_Disable();
			  Motor2_Home();
		  }
		  if(Motor2.pos == 0) { nextEtchingState = APPROACH; }
		  break;

	  case APPROACH:
		  if(SelectState(APPROACH)) {
			  Tip_5V();
			  Tip_Enable();
		  }
		  // Wykryto taflę cieczy (przepływa prąd).
		  if(Tip_Current() > minCurrentMiliAmp) { nextEtchingState = DIVE; }

		  if(Motor2.pos == Motor2.setPos && !Motor2_MaxPos()) {
			  Motor2.setPos -= 1;
		  }
		  break;

	  case DIVE:
		  if(SelectState(DIVE)) {
			  Tip_5V();
			  Tip_Disable();
			  Motor2.setPos = Motor2.pos - (double)(var_depth) / 5.0;
		  }
		  if(Motor2.pos == Motor2.setPos) { nextEtchingState = ETCH; }
		  break;

	  case ETCH:
		  if(SelectState(ETCH)) {
			  if(voltageSelection)
				  Tip_5V();
			  else
				  Tip_24V();
			  Tip_Enable();
			  etchStartPosition = Motor2.pos;
		  }
		  if(stepTime_cnt * 2 >= ((double)(var_step) / (double)(var_depth * 1.0)) * (var_etchTime * 1000.0)) {
			  stepTime_cnt = 0;
			  Motor2.setPos += (double)(var_step) / 5;
		  }

		  if(etchTime_cnt * 2 >= var_etchTime * 1000.0) {
			  if(var_polishTime > 0)
				  nextEtchingState = POLISH;
			  else
				  nextEtchingState = IDLE;
		  }
		  break;
	  case POLISH:
		  if(SelectState(POLISH)) {
			  Motor2.setPos = etchStartPosition;
			  Tip_Disable();
		  }

		  if(Motor2.pos == etchStartPosition) {
			  if(polishTime_cnt * 2 >= var_polishTime) {
				  nextEtchingState = IDLE;
			  } else {
				  Tip_24V();
				  Tip_Enable();
			  }
		  }

		  break;
	  default:
	  case None:
		  NAL_NaMiMenu_OLED_Update();
		  nextEtchingState = IDLE;
		  break;
	  }

	  if(!etching) {
		  nextEtchingState = IDLE;
	  }

    /* USER CODE END WHILE */

    /* USER CODE BEGIN 3 */
  }
  /* USER CODE END 3 */
}

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


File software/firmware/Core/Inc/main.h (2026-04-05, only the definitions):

#define BOARD_BTN_Pin GPIO_PIN_13
#define BOARD_BTN_GPIO_Port GPIOC
#define OLED_RESET_Pin GPIO_PIN_0
#define OLED_RESET_GPIO_Port GPIOA
#define OLED_DC_Pin GPIO_PIN_1
#define OLED_DC_GPIO_Port GPIOA
#define OLED_CS_Pin GPIO_PIN_4
#define OLED_CS_GPIO_Port GPIOA
#define M_ENABLE_Pin GPIO_PIN_6
#define M_ENABLE_GPIO_Port GPIOA
#define ENCODER_BTN_Pin GPIO_PIN_7
#define ENCODER_BTN_GPIO_Port GPIOA
#define ENCODER_BTN_EXTI_IRQn EXTI9_5_IRQn
#define LIMIT_SWITCH_1_Pin GPIO_PIN_10
#define LIMIT_SWITCH_1_GPIO_Port GPIOB
#define OLED_SPI2_SCK_Pin GPIO_PIN_13
#define OLED_SPI2_SCK_GPIO_Port GPIOB
#define OLED_SPI2_MOSI_Pin GPIO_PIN_15
#define OLED_SPI2_MOSI_GPIO_Port GPIOB
#define LED_Pin GPIO_PIN_6
#define LED_GPIO_Port GPIOC
#define ENCODER_SIGA_Pin GPIO_PIN_8
#define ENCODER_SIGA_GPIO_Port GPIOA
#define ENCODER_SIGA_EXTI_IRQn EXTI9_5_IRQn
#define ENCODER_SIGB_Pin GPIO_PIN_9
#define ENCODER_SIGB_GPIO_Port GPIOA
#define TIP_EN_Pin GPIO_PIN_12
#define TIP_EN_GPIO_Port GPIOA
#define V_SELECT_Pin GPIO_PIN_10
#define V_SELECT_GPIO_Port GPIOC
#define DIR_1_Pin GPIO_PIN_3
#define DIR_1_GPIO_Port GPIOB
#define STEP_1_Pin GPIO_PIN_4
#define STEP_1_GPIO_Port GPIOB
#define DIR_2_Pin GPIO_PIN_5
#define DIR_2_GPIO_Port GPIOB
#define STEP_2_Pin GPIO_PIN_6
#define STEP_2_GPIO_Port GPIOB

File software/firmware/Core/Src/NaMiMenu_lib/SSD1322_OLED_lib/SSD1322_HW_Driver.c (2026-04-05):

/**
 ****************************************************************************************
 *
 * \file SSD1322_HW_Driver.c
 *
 * \brief Hardware dependent functions for SSD1322 OLED display.
 *
 * This file contains functions that rely on hardware of used MCU. In this example functions
 * are filled with STM32F411RE hardware implementation. To use this library on any other MCU
 * you just have to provide its hardware implementations of functions from this file and higher
 * level functions should work without modification.
 *
 * Copyright (c) 2025 KN NaMi
 *
 * Copyright (C) 2020 Wojciech Klimek
 * MIT license:
 * https://github.com/wjklimek1/SSD1322_OLED_library
 *
 ****************************************************************************************
 */

//=================== Include hardware HAL libraries =====================//
#include "stm32g4xx_hal.h"
#include "main.h"
//#include "spi.h"

#include "../SSD1322_OLED_lib/SSD1322_HW_Driver.h"
#include "../../NaMiMenu_lib/NaMiMenu.h"

//====================== CS pin low ========================//
/**
 *  @brief Drives CS (Chip Select) pin of SPI interface low.
 *
 *  CS pin may be also signed as "SS" or "NSS"
 */
void SSD1322_HW_drive_CS_low()
{
	HAL_GPIO_WritePin(NaMiMenu_OLED_CS.port, NaMiMenu_OLED_CS.pin, 0);
}

//====================== CS pin high ========================//
/**
 *  @brief Drives CS (Chip Select) pin of SPI interface high.
 *
 *  CS pin may be also signed as "SS" or "NSS"
 */
void SSD1322_HW_drive_CS_high()
{
	HAL_GPIO_WritePin(NaMiMenu_OLED_CS.port, NaMiMenu_OLED_CS.pin, 1);
}

//====================== DC pin low ========================//
/**
 *  @brief Drives DC (Data/Command) pin of OLED driver low.
 *
 *  High state is for data and low state is for command.
 */
void SSD1322_HW_drive_DC_low()
{
	HAL_GPIO_WritePin(NaMiMenu_OLED_DC.port, NaMiMenu_OLED_DC.pin, 0);
}

//====================== DC pin high ========================//
/**
 *  @brief Drives DC (Data/Command) pin of of OLED driver high.
 *
 *  High state is for data and low state is for command.
 */
void SSD1322_HW_drive_DC_high()
{
	HAL_GPIO_WritePin(NaMiMenu_OLED_DC.port, NaMiMenu_OLED_DC.pin, 1);
}

//====================== RESET pin low ========================//
/**
 *  @brief Drives RESET pin of of OLED driver low.
 *
 *  Logic low on RESET resets OLED driver.
 */
void SSD1322_HW_drive_RESET_low()
{
	HAL_GPIO_WritePin(NaMiMenu_OLED_RESET.port, NaMiMenu_OLED_RESET.pin, 0);
}

//====================== RESET pin high ========================//
/**
 *  @brief Drives RESET pin of of OLED driver high.
 *
 *  Logic low on RESET resets OLED driver.
 */
void SSD1322_HW_drive_RESET_high()
{
	HAL_GPIO_WritePin(NaMiMenu_OLED_RESET.port, NaMiMenu_OLED_RESET.pin, 1);
}

//====================== Send single SPI byte ========================//
/**
 *  @brief Transmits single byte through SPI interface.
 *
 *  @param[in] byte_to_transmit byte that will be transmitted through SPI interface
 */
void SSD1322_HW_SPI_send_byte(uint8_t byte_to_transmit)
{
	HAL_SPI_Transmit(NaMiMenu_OLED_hspi, &byte_to_transmit, 1, 10);
}

//====================== Send array of SPI bytes ========================//
/**
 *  @brief Transmits array of bytes through SPI interface.
 *
 *  @param[in] array_to_transmit array of bytes that will be transmitted through SPI interface
 *  @param[in] array_size amount of bytes to transmit
 */
void SSD1322_HW_SPI_send_array(uint8_t *array_to_transmit, uint32_t array_size)
{
	HAL_SPI_Transmit(NaMiMenu_OLED_hspi, array_to_transmit, array_size, 100);
}

//====================== Milliseconds delay ========================//
/**
 *  @brief Wait for x milliseconds.
 *
 *  NOTE: This function is only used in initialization sequence to pull reset down and high
 *  and later to wait for Vdd stabilization. It takes time ONLY on startup (around 200ms)
 *  and is NOT USED during normal operation.
 *
 *  @param[in] milliseconds time to wait
 */
void SSD1322_HW_msDelay(uint32_t milliseconds)
{
	HAL_Delay(milliseconds);
}

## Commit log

2025-02-10 add corner bracker
    [corner-mount.FCStd]
2025-02-12 add L-mount
    [L-mount.FCStd]
2025-02-24 add frame assembly
    [L-mount.FCStd, assembly.FCStd, assembly_frame.FCStd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]
2025-02-25 add stm with voltage converte
    [mainboard.kicad_pcb, mainboard.kicad_sch]
2025-02-28 Add USB C port and integrate it with uC
    [mainboard.kicad_sch]
2025-03-03 add psu-mount
    [assembly-frame.FCStd, assembly.FCStd, assembly_frame.FCStd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]
2025-03-30 add stepsticks
    [mainboard.kicad_sch]
2025-03-30 add IDA
    [mainboard.kicad_pcb, mainboard.kicad_sch]
2025-03-30 Add TIP Voltage Control
    [mainboard.kicad_pcb, mainboard.kicad_sch]
2025-03-31 Create pcb
    [mainboard.kicad_pcb, mainboard.kicad_sch]
2025-04-11 fix assembly
    [L-mount.FCStd, assembly-frame.FCStd, corner-mount.FCStd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]
2025-07-07 Minor Schematic & Major PCB Rework
    [mainboard.kicad_pcb, mainboard.kicad_sch]
2025-07-08 Update PCB
    [mainboard.kicad_pcb, mainboard.kicad_sch]
2025-07-08 Update PCB Change Buck Converter Vout from 3.3V to 5V
    [mainboard.kicad_pcb, mainboard.kicad_sch]
2025-07-09 Update PCB | Requested Changes
    [mainboard.kicad_pcb, mainboard.kicad_sch]
2025-07-09 Change OLED Connector Size
    Changed size of an OLED connector from 2.54mm to 2.00mm to match its size from other related project.
    [mainboard.kicad_pcb, mainboard.kicad_sch]
2025-07-24 Add Limit Switches
    [mainboard.kicad_pcb, mainboard.kicad_sch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]
2025-07-24 Change Limit Switch Connectors
    Change from 2 pin to 3 pin connectors
    [mainboard.kicad_pcb, mainboard.kicad_sch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]
2025-09-04 Assembly
    Wszystkie elementy drukowane są już zawarte. Pozostało uzupełnienie o łożyska itp.
    [Screen_v3.FCStd, base.FCStd, bearing_holder.FCStd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]
2025-11-09 standarize repo
    [L-mount.FCStd, assembly-frame.FCStd, corner-mount.FCStd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]
2025-12-21 Add Code
    Still have some bugs, however was tested and device is etching properly
    [NaMiMenu.c]
2026-03-14 New PCB version
    [mainboard.kicad_pcb, mainboard.kicad_sch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]
2026-11-11 init(firmware): Initialize rebase to Raspberry Pico target
2026-11-12 feat(display)!: Implement SSD1322 display driver and graphics library
    - Added `ssd1322_X.rs` for the SSD1322 display API
    - Added unit tests for the graphics library to verify functionality and correctness of drawing operations (though will probably delete them whenever convenient).
2026-11-12 docs(software): Update to match the new rebase and rewrite.
    Since we're rebasing from STM32G474CEUX to an unknown RP Pico and rewriting to match the components, i took on also deciding to write it all in Rust to prioritise safety

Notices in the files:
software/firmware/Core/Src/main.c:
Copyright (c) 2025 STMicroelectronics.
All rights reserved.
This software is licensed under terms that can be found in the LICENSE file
